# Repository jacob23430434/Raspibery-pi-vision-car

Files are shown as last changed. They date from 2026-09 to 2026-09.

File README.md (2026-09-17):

# Raspberry Pi 5 Vision Car

A four-week university **Engineering Week** group project: a small line-following and teleoperated car built around an **Arduino** (motor & sensor MCU) and a **Raspberry Pi 5** (control and live telemetry). This repository holds the firmware, the Raspberry Pi scripts, the circuit schematics and a Webots simulation — organised from the original, sprawling working folder.

> This is coursework. It contains both the final working code and the intermediate experiments that led to it (encoder tuning, sensor calibration, abandoned branches kept out). Treat it as a record of the build, not production code.

## Overview

| Layer | Role |
|---|---|
| Arduino (car MCU) | Motor & encoder control, line following, sensors, Bluetooth/RF comms |
| Raspberry Pi 5 (Python) | PS5-controller teleoperation, live position plotting, PID simulation |
| Schematics | Fritzing breadboard layouts + KiCad boards (RF module, MPU-6050) |
| Simulation | Webots e-puck line-following project + a Python sensor/PID model |

## Demo

The live 3D position of the car, plotted on the Raspberry Pi from the IMU telemetry (see [`raspberry-pi/vision`](raspberry-pi/vision)):

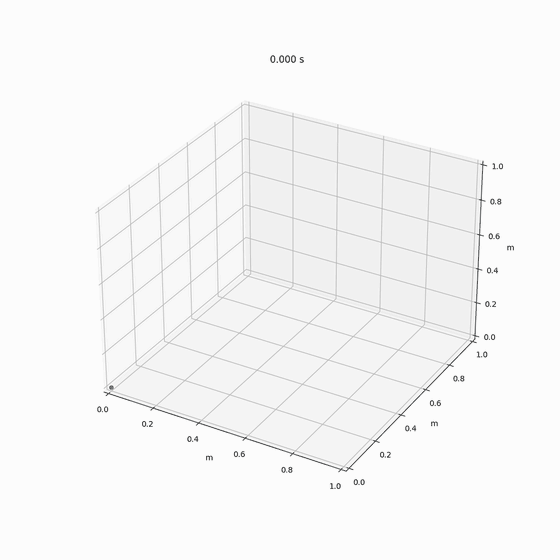
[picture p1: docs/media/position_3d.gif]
Live 3D position of the car


More clips in [`docs/media/`](docs/media):

| Clip | What it shows |
|---|---|
| [`car_demo.mp4`](docs/media/car_demo.mp4) | Full demo-session recording (3 min, 720p, 32 MB) |
| [`pid_sim_demo.mp4`](docs/media/pid_sim_demo.mp4) | The Python PID line-follower simulation running (38 MB) |
| [`mpu6050_yaw.mp4`](docs/media/mpu6050_yaw.mp4) | Slide walkthrough of the MPU-6050 yaw control loop (100 Hz) |

## What the car can do

- **Drive & measure** — DC motors with encoders, straight-line and turning control, speed measurement
- **Follow a line** — 8-channel IR line sensor (I2C address `0x09`) with PID steering
- **Sense** — MPU-6050 (acceleration → velocity → displacement), voltage, buzzer, EC11 rotary encoder, buttons, display
- **Communicate** — UART, HC-06 Bluetooth, 433 MHz RF (transmit/receive)
- **Teleoperate** — a PlayStation 5 controller drives the car over Bluetooth serial
- **Visualise** — the Pi plots the car's real-time XY position from IMU-integrated telemetry

## Repository layout

```
.
├── firmware/                 # Arduino sketches (car MCU)
│   ├── motors_encoders/      # motor, encoder, straight-line & speed control
│   ├── line_following/       # IR line sensor + PID
│   ├── sensors/              # MPU-6050, voltage, buzzer, EC11, screen
│   ├── communication/        # UART, HC-06 Bluetooth, RF 433 MHz
│   ├── ps5_controller/       # PS5 gamepad over Bluetooth
│   └── misc/                 # blink/fade and loose demos
├── raspberry-pi/
│   ├── control/              # PS5 -> Bluetooth serial, debug helpers
│   ├── vision/               # live XY-position plotting, sensor calibration
│   └── simulation/           # Python model of the line sensor + PID tuning
├── schematics/               # Fritzing (.fzz) + KiCad (RF, MPU-6050)
├── simulation/               # Webots e-puck line-following world & controllers
├── README.md
└── .gitignore
```

### Firmware highlights

| Sketch | What it does |
|---|---|
| `line_following/LineFollowTest.ino` | Reads the 8-channel IR sensor over I2C and prints the array |
| `line_following/topic2_code_PID.ino` | PID line-following control |
| `motors_encoders/update_motor_control.ino` | Motor + encoder closed-loop driving |
| `communication/Transmit/Transmit.ino` + `Receive/Receive.ino` | 433 MHz RF link |
| `communication/HC-06/HC-06.ino` | Bluetooth serial |
| `sensors/mpu_a-v-d_code/mpu_a-v-d_code.ino` | MPU-6050 acceleration → velocity → displacement |
| `ps5_controller/ps5_arduino.ino` | Receives PS5 commands over Bluetooth |

### Raspberry Pi highlights

| Script | What it does |
|---|---|
| `control/ps5_control.py` | Reads a PS5 gamepad (pygame) and sends `S/L/R/...` commands over HC-06 serial |
| `vision/3dposition.py` | Parses the car's JSON telemetry and plots its XY position live (matplotlib) |
| `simulation/simulation/sim.py` | Simulates the track + IR sensor readings and tunes PID gains (`best_params.json`) |

## Schematics

- **Fritzing** — breadboard wiring for LED, buzzer, rotary encoder and the Task 3.2 circuit (`.fzz`)
- **KiCad** — `RF` (433 MHz module) and `MPU-6050` boards (`.kicad_sch` / `.kicad_pcb`)

## Simulation

`simulation/` is a Webots project for the **e-puck** robot used to prototype line following before flashing the car. It contains the world (`worlds/e-puck_line_demo.wbt`) and the controller / remote-control / robot-window plugins as C++ source. Compiled binaries (`.dll`, `.exe`, `.o`) are not tracked — Webots rebuilds them from the `Makefile`s.

## Notes

- **Reports are intentionally not included** — the lab reports and logbook contain the authors' names and student IDs. They remain in the original local folder.
- Calibration data (`.csv`/`.txt`) and media (`.mp4` recordings, photos) are also kept out of the repo; only source and schematics are tracked.
- Some sketches are rough or leftover experiments (e.g. `firmware/motors_encoders/edition*.ino`); they are kept for reference.
- Comms parameters vary per sketch — Bluetooth uses `SoftwareSerial` at 9600 baud, RF uses 433 MHz modules; check each sketch's header.

## Built with

- [Arduino](https://www.arduino.cc/) — car MCU firmware
- [Raspberry Pi 5](https://www.raspberrypi.com/) — control & telemetry (Python 3, `pyserial`, `pygame`, `matplotlib`, `numpy`)
- [Webots](https://cyberbotics.com/) — e-puck robot simulation
- [Fritzing](https://fritzing.org/) / [KiCad](https://www.kicad.org/) — schematics
- [i2cdevlib MPU-6050](https://github.com/jrowberg/i2cdevlib) — IMU example code

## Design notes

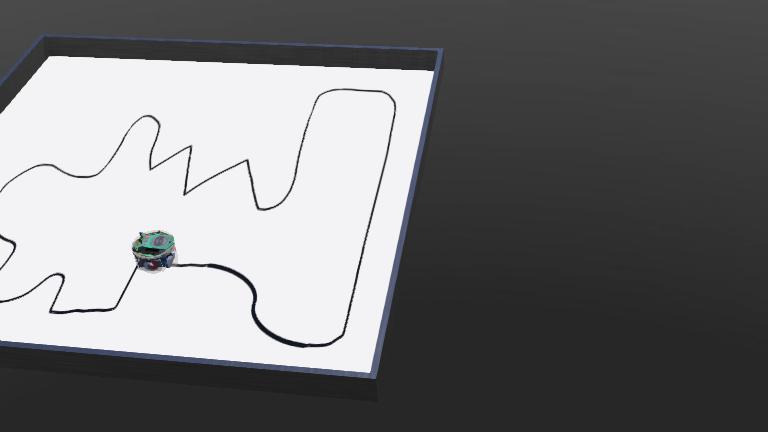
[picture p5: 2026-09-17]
simulation/worlds/.e-puck_line_demo.jpg

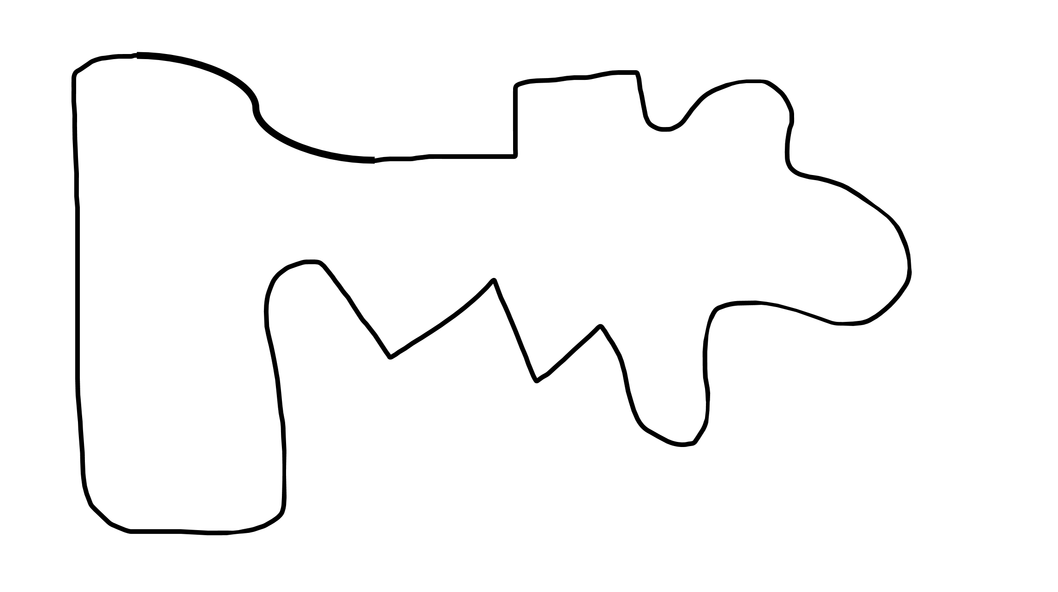
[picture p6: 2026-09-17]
simulation/worlds/textures/Screenshot 2025-12-18 180749.png

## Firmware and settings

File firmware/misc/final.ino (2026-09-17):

#include <LiquidCrystal.h>
#include <Wire.h>
#include <MsTimer2.h>

// ====== Pins ======
#define MIC_INT_PIN 2
#define LED_PIN 13
#define BUZZER_PIN 8
#define DIR_SWITCH_PIN A7
#define LED A1
#define BUTTON_PIN 9
#define PUSH1 3
#define PUSH2 10

const int rs=12,en=11,d4=4,d5=5,d6=6,d7=7;
LiquidCrystal lcd(rs,en,d4,d5,d6,d7);

// ====== MsTimer2 RT setup ======
volatile bool updateFlag = false;
const unsigned long controlInterval = 5; // 5ms → 200Hz

// ====== Small car parameters ======
int steerForward = 5;    // Forward steering compensation
int steerBackward = -5;  // Backward steering compensation
float distanceCompensation = 1.33; // Distance correction factor
int sp = 50;             // Default speed

// ====== I2C motor constants ======
constexpr uint8_t MOTOR_ADDR = 0x2A;
constexpr int8_t WHEEL_SENSE[4] = {-1, 1, 1, -1};
constexpr int8_t LINEAR_TRIM[4] = {-2, 6, -2, 6};
constexpr char CMD_SET_SPEED_DIR = 'b';
constexpr char CMD_HALT_ALL     = 'h';
constexpr char TARGET_ALL       = 'a';

// ====== Movement control ======
bool moving = false;
bool forward = true;
float targetMeters = 0;
unsigned long moveStartTime = 0;
unsigned long moveDuration = 0;

// ====== Variables ======
volatile int step=0;
uint8_t lastState;
int speedValue=50;
float metersValue=2.0;
int cyclesValue=3;
char currentTask='B';   // Default TaskB
bool isPlaying=false;
volatile bool triggered=false;
bool locked=false;
unsigned long lockStartTime=0;
const unsigned long lockDuration=6000;

enum MenuMode { MODE_SPEED, MODE_TASK_PARAM };
MenuMode menuMode = MODE_SPEED;
unsigned long lcdLastUpdate=0;

// ====== Motor functions ======
static inline int16_t clamp100(int v){
  if(v>100) return 100;
  if(v<-100) return -100;
  return v;
}

static inline void writeUint16LE(uint16_t x){
  Wire.write((uint8_t)(x & 0xFF));
  Wire.write((uint8_t)(x >> 8));
}

void driveAll(int m1, int m2, int m3, int m4){
  int req[4] = {m1,-m2,-m3,m4};
  char dir[4];
  uint16_t mag[4];

  for(uint8_t i=0;i<4;i++){
    int v=req[i];
    v+=(v>=0)?LINEAR_TRIM[i]:-LINEAR_TRIM[i];
    v=clamp100(v);
    int adj = clamp100(v * WHEEL_SENSE[i]);
    dir[i]=(adj>=0)?'f':'r';
    mag[i]=(uint16_t)(adj>=0?adj:-adj);
  }

  Wire.beginTransmission(MOTOR_ADDR);
  Wire.write(CMD_SET_SPEED_DIR); Wire.write(TARGET_ALL);
  Wire.write(dir[0]); Wire.write(dir[2]); Wire.write(dir[1]); Wire.write(dir[3]);
  writeUint16LE(mag[0]); writeUint16LE(mag[2]); writeUint16LE(mag[1]); writeUint16LE(mag[3]);
  Wire.endTransmission();
}

void stopAll(){
  Wire.beginTransmission(MOTOR_ADDR);
  Wire.write(CMD_HALT_ALL);
  Wire.write(TARGET_ALL);
  Wire.endTransmission();
}

// ====== Movement control using non-blocking & MsTimer2 ======
void startMove(bool fwd, int speed, float meters){
    forward = fwd;
    sp = speed;
    targetMeters = meters;
    moveDuration = meters * distanceCompensation * 1000;
    moveStartTime = millis();
    moving = true;
}

void updateMove(){
    if(!moving) return;

    int offset = forward ? steerForward : steerBackward;
    int m1, m2, m3, m4;

    if(offset > 0){
        m1 = sp; m3 = sp;
        m2 = sp - offset; m4 = sp - offset;
    } else if(offset < 0){
        m1 = sp + offset; m3 = sp + offset;
        m2 = sp; m4 = sp;
    } else {
        m1 = m2 = m3 = m4 = sp;
    }

    if(!forward){
        m1 = -m1; m2 = -m2; m3 = -m3; m4 = -m4;
    }

    driveAll(m1, m2, m3, m4);

    if(millis() - moveStartTime >= moveDuration){
        stopAll();
        moving = false;
    }
}

// ====== Timer ISR ======
void controlISR(){
    updateFlag = true;
}

// ====== Clap detection ======
void clapISR(){
  if(!locked) triggered=true;
}

// ====== Buzzer ======
unsigned long buzzerStart=0;
unsigned long buzzerDuration=0;
bool buzzerActive=false;

void playBuzzer(int freq, int duration){
    tone(BUZZER_PIN,freq,duration);
    buzzerStart = millis();
    buzzerDuration = duration;
    buzzerActive = true;
}

void updateBuzzer(){
    if(buzzerActive && millis()-buzzerStart >= buzzerDuration){
        noTone(BUZZER_PIN);
        buzzerActive = false;
    }
}

// ====== LCD ======
void updateScreen(){
  lcd.clear();
  lcd.setCursor(0,0); 
  lcd.print("Task: "); lcd.print(currentTask);
  lcd.setCursor(7,0); 
  if(currentTask=='A') lcd.print("C:"); else lcd.print("M:");
  lcd.print((currentTask=='A')?cyclesValue:metersValue,1);

  lcd.setCursor(0,1); 
  lcd.print("Speed:"); lcd.print(speedValue); lcd.print("% ");

  lcd.setCursor(11,1);
  bool dirState=(analogRead(DIR_SWITCH_PIN)>1000);
  lcd.print(dirState?"FC":"BAC");

  lcd.setCursor(12,0);
  if(isPlaying){lcd.print("Run"); digitalWrite(LED_PIN,HIGH);}
  else{lcd.print("Stop"); digitalWrite(LED_PIN,LOW);}
}

// ====== Setup ======
void setup(){
    Wire.begin();
    stopAll();
    Serial.begin(115200);

    pinMode(LED,OUTPUT);
    pinMode(PUSH1,INPUT);
    pinMode(PUSH2,INPUT);
    pinMode(BUTTON_PIN,INPUT);
    pinMode(LED_PIN,OUTPUT);
    pinMode(BUZZER_PIN,OUTPUT);
    pinMode(DIR_SWITCH_PIN,INPUT);
    pinMode(MIC_INT_PIN,INPUT);

    attachInterrupt(digitalPinToInterrupt(MIC_INT_PIN),clapISR,RISING);

    lastState=(digitalRead(PUSH2)<<1)|digitalRead(PUSH1);

    lcd.begin(16,2);
    updateScreen();

    MsTimer2::set(controlInterval, controlISR); // 5ms → 200Hz
    MsTimer2::start();
}

// ====== Loop ======
void loop(){
    // 1. MsTimer2 control update
    if(updateFlag){
        updateFlag = false;
        updateMove();
    }

    // 2. Update buzzer
    updateBuzzer();

    // 3. Clap-triggered Task B
    bool dirForward = (analogRead(DIR_SWITCH_PIN)>1000);
    if(triggered && !isPlaying && !locked && currentTask=='B'){
        triggered=false;
        locked=true;
        lockStartTime=millis();
        isPlaying=true;
        updateScreen();

        digitalWrite(LED,HIGH);
        playBuzzer(1000,200); delay(250);
        playBuzzer(800,200); delay(250);

        startMove(dirForward,speedValue,metersValue);
        while(moving){ 
            if(updateFlag){ updateFlag=false; updateMove(); }
            updateBuzzer();
        }

        playBuzzer(600,400); delay(500);
        playBuzzer(1200,400); delay(500);
        digitalWrite(LED,LOW);

        isPlaying=false;
        updateScreen();
    }

    // 4. Automatic unlock
    if(locked && millis()-lockStartTime>=lockDuration) locked=false;

    // 5. Button for menu/task selection
    static unsigned long pressStart=0;
    if(digitalRead(BUTTON_PIN)==LOW){
        pressStart = millis();
        while(digitalRead(BUTTON_PIN)==LOW); // Wait release
        unsigned long t = millis()-pressStart;

        if(t < 500){ // Short press → toggle menu
            menuMode = (menuMode==MODE_SPEED)?MODE_TASK_PARAM:MODE_SPEED;
        } else {    // Long press → toggle task
            currentTask = (currentTask=='A')?'B':'A';
        }
        updateScreen();
    }

    // 6. Rotary encoder
    uint8_t cur=(digitalRead(PUSH2)<<1)|digitalRead(PUSH1);
    if(cur!=lastState){
        if ((lastState==0b00 && cur==0b01) ||
            (lastState==0b01 && cur==0b11) ||
            (lastState==0b11 && cur==0b10) ||
            (lastState==0b10 && cur==0b00)) step++;
        else step--;
        lastState=cur;

        if(cur==0b00){
            if(menuMode==MODE_SPEED){
                speedValue=constrain(speedValue+(step>0?1:-1),1,100);
            }else{
                if(currentTask=='A') cyclesValue=constrain(cyclesValue+(step>0?1:-1),1,20);
                else metersValue=constrain(metersValue+(step>0?0.1:-0.1),1.0,10.0);
            }
            step=0;
            if(millis()-lcdLastUpdate>=100){
                updateScreen();
                lcdLastUpdate=millis();
            }
        }
    }
}

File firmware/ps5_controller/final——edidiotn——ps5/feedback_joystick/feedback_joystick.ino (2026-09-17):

#include <Wire.h>
#include <SoftwareSerial.h>

SoftwareSerial BT(10, 11); // RX, TX

//-------------------- 参数 --------------------//
int speed = 100;
unsigned int meter = 1000;
unsigned int mval;
int differ = 20;
// encoder
#define encoder_shift 0x80000000UL
unsigned long e1_raw, e2_raw, e3_raw, e4_raw;

unsigned long lastEncTime = 0;
long e1_prev, e2_prev, e3_prev, e4_prev;
float v1, v2, v3, v4, v_avg;



//================================================
// 初始化
//================================================
void setup() {
    Wire.begin();
    BT.begin(9600);
    Serial.begin(115200);
    
    updateEnc(); // 初始化一次避免垃圾值

    mval = meter * 1083;
    Serial.println("PS5 Bluetooth control ready");
    car_control(0, 0);


}

//================================================
void loop(){

    // ============= 蓝牙控制区域（保持原样） =============

    if (BT.available()) {
        char cmd = BT.read();
        controlBT(cmd);
    }

    // ============= 速度计算核心 =============
    if(millis() - lastEncTime >= 500) {   // 100Hz
        lastEncTime = millis();
        updateSpeed();
    }
    updateEnc();
}

//================================================
// encoder auto stop
//================================================
void car_stop(){
    unsigned int average = (cnt(e1_raw)+cnt(e2_raw)+cnt(e3_raw)+cnt(e4_raw))/4;
    unsigned int val = -(average-65555);
    if(val >= mval){
        car_control(0,0);
    }
}

long cnt(unsigned long raw){
    return (long)raw - (long)encoder_shift;
}

//================================================
// encoder 读取
//================================================
void updateEnc(){
    // read e1 e2
    Wire.beginTransmission(42);
    Wire.write("i0");
    Wire.endTransmission();
    delay(1);

    Wire.requestFrom(42, 8);
    e1_raw = read32();
    e2_raw = read32();

    // read e3 e4
    Wire.beginTransmission(42);
    Wire.write("i5");
    Wire.endTransmission();
    delay(1);

    Wire.requestFrom(42, 8);
    e3_raw = read32();
    e4_raw = read32();
}

unsigned long read32(){
    unsigned long v = 0;
    v |= (unsigned long)Wire.read();
    v |= (unsigned long)Wire.read()<<8;
    v |= (unsigned long)Wire.read()<<16;
    v |= (unsigned long)Wire.read()<<24;
    return v;
}

//================================================
// **保持原样 — car_control**
//================================================
void car_control(float a, float b){
  Wire.beginTransmission(42);
  Wire.write("baffff");

  // Motor1: 右前
  Wire.write((int)b);
  Wire.write(0);

  // Motor2: 右后
  Wire.write((int)b);
  Wire.write(0);

  // Motor3: 左前
  Wire.write((int)a);
  Wire.write(0);

  // Motor4: 左后
  Wire.write((int)a);
  Wire.write(0);

  Wire.endTransmission();
  delay(1);
}


void car_control1(float a, float b){
  Wire.beginTransmission(42);
  Wire.write("barrrr");

  // Motor1: 右前
  Wire.write((int)b);
  Wire.write(0);

  // Motor2: 右后
  Wire.write((int)b);
  Wire.write(0);

  // Motor3: 左前
  Wire.write((int)a);
  Wire.write(0);

  // Motor4: 左后
  Wire.write((int)a);
  Wire.write(0);

  Wire.endTransmission();
  delay(1);
}
//================================================
// **保持原样 — turn 旋转**
//================================================
void car_turn(){
  Wire.beginTransmission(42);
  Wire.write("tr");

  for(int i=0;i<=3;i++){
    Wire.write(speed);
    Wire.write(0);
  }

  for(int i=0;i<=3;i++){
    Wire.write(256);
    Wire.write(100);
    Wire.write(0);
    Wire.write(0);
  }

  Wire.endTransmission();
  delay(1);
}
void car_turn1(){
  Wire.beginTransmission(42);
  Wire.write("tl");

  for(int i=0;i<=3;i++){
    Wire.write(speed);
    Wire.write(0);
  }

  for(int i=0;i<=3;i++){
    Wire.write(256);
    Wire.write(100);
    Wire.write(0);
    Wire.write(0);
  }

  Wire.endTransmission();
  delay(1);
}
void controlBT(char cmd){
    Serial.print("CMD = ");
    Serial.println(cmd);

    switch(cmd){
        case 'F':
            car_control(speed, speed);
            break;

        case 'B':
            car_control1(speed, speed);
            break;

        case 'L':
            car_turn();
            break;

        case 'R':
            car_turn1();
            break;

        case 'X':
            car_control(speed, speed-50);
            break;

        case 'Y':
            car_control(speed-50, speed);
            break;

        case 'S':
        default:
            car_control(0,0);
            break;
    }
}
void updateSpeed(){
    // 更新编码器原始数据
    updateEnc();

    long c1 = cnt(e1_raw);
    long c2 = cnt(e2_raw);
    long c3 = cnt(e3_raw);
    long c4 = cnt(e4_raw);

    // Δcount
    long d1 = c1 - e1_prev;
    long d2 = c2 - e2_prev;
    long d3 = c3 - e3_prev;
    long d4 = c4 - e4_prev;

    // 存当前值用于下一次
    e1_prev = c1;
    e2_prev = c2;
    e3_prev = c3;
    e4_prev = c4;

    // 时间固定100ms → 0.5s
    const float dt = 0.5f;

    // 根据 1083 count = 1m
    // → m/s = Δcount / 1083 / dt
    v1 = (float)d1 / 1083.0 / dt;
    v2 = (float)d2 / 1083.0 / dt;
    v3 = (float)d3 / 1083.0 / dt;
    v4 = (float)d4 / 1083.0 / dt;

    v_avg = (v1+v2+v3+v4)/-4.0;

    Serial.print("V1=");
    Serial.print(v1,3);
    Serial.print("\tV2=");
    Serial.print(v2,3);
    Serial.print("\tV3=");
    Serial.print(v3,3);
    Serial.print("\tV4=");
    Serial.print(v4,3);
    Serial.print("\tAVG=");
    Serial.println(v_avg,3);

    BT.println(v_avg, 3);

}
